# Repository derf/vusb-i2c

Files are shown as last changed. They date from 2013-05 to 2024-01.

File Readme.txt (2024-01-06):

VUSB-based USB to I2C conversion board.

This setup assumes that you have a VUSB board with level conversion on D+ and D-
<http://vusb.wdfiles.com/local--files/hardware/level-conversion-with-zener.gif>,
use an ATTiny and have D+ is connected to INT0, D- to INT1,
SDA to PB6 and SCL to PB7. hardware pull-ups must be connected to SDA and SCL.

The commandline utilities are meant to be similar to the i2c-tools utilities.
vusb-i2cdetect can be used to scan a bus, while vusb-i2cget and vusb-i2cset
read/write data.

For instance, to set a MicroMoody's color to yellow:
> vusb-i2cset 17 0 0 255 255 0 0 1

Or, to read out the temperature from a TC74 thermal sensor:
> vusb-i2cget 77 1 0

The original VUSB readme follows:

-----

This is the README file for the PowerSwitch USB device.

PowerSwitch is an example application using Objective Development's
firmware-only USB driver for Atmel's AVR microcontrollers. It provides 8 bits
of parallel output intended to switch e.g. the power supply to electronic
devices. The PowerSwitch firmware is accompanied by a command line tool to
control the device.

Objective Development's USB driver is a firmware-only implementation of the
USB 1.1 standard (low speed device) on cheap single chip microcomputers of
Atmel's AVR series, such as the ATtiny2313 or even some of the small 8 pin
devices. It implements the standard to the point where useful applications
can be implemented. See the file "firmware/usbdrdv/usbdrv.h" for features
and limitations.

BUILDING AND INSTALLING

Both, the firmware and Unix command line tool are built with "make". You may
need to customize both makefiles.

Firmware:
The firmware for PowerSwitch requires avr-gcc and avr-libc (a C-library for
the AVR controller). Please read the instructions at
http://www.nongnu.org/avr-libc/user-manual/install_tools.html for how to
install the GNU toolchain (avr-gcc, assembler, linker etc.) and avr-libc.
If you are on Windows, download WinAVR (see http://winavr.sourceforge.net/).
For the Mac, we recommend AVR MacPack at http://www.obdev.at/avrmacpack/.

Once you have the GNU toolchain for AVR microcontrollers installed, you can
run "make" in the subdirectory "firmware". You may have to edit the Makefile
to use your preferred downloader with "make flash". Our current version is
built for avrdude with our AVR-Doper programmer.

Command Line Tool on Unix:
The command line tool requires libusb. Please download libusb from
http://libusb.sourceforge.net/ and install it before you compile. Change to
directory "commandline", check the settings in Makefile and edit them as
appropriate. Then type "make" to build the executable "powerSwitch" which can
be used to control the device.

Command Line Tool on Windows:
The command line tool uses libusb-win32. Please download libusb-win32 from
http://libusb-win32.sourceforge.net/. The small package
(libusb-win32-device-bin) should be sufficient. We need usb.h and libusb.a for
gcc (or your favorite compiler). Make sure that usb.h is in the include path
and libusb.a in the library search path (edit Makefile to achieve this).
Although it should be possible to compile the command line tool with any
compiler, we recommend that you use MSYS (to run make and other Unix tools)
and MinGW (for the gcc toolchain). Both can be downloaded for free from
http://www.mingw.org/.

If you want to develop Windows drivers without libusb-win32, see our
"Automator" project for an example.

WORKING WITH POWERSWITCH

Once you have compiled and flashed the firmware and compiled the command line
tool, you can move on to the fun part: Connect the device to a free USB port
of your computer or USB-hub. You should now be able to find the device in
any USB analyzer tool, e.g. SystemProfiler on Mac OS X. If you connect it
to a Windows PC, the "New Hardware" dialog will pop up and you can create
the appropriate info files with libusb-win32's inf-wizard.

The next step is to try the command line tool, e.g.:

    ./powerSwitch off 3

to turn off port 3 (all ports are on when the device has been cleared) or

    for i in 0 1 2 3 4 5 6 7; do ./powerSwitch off $i; done

in an sh or bash (not csh or tcsh) type shell to turn off all ports.

You can also switch a port on or off temporarily. Try

    ./powerSwitch on 0 2.5

to activate port 0 for two and a half seconds.

FILES IN THE DISTRIBUTION

Readme.txt ........ The file you are currently reading.
firmware .......... Source code of the controller firmware.
firmware/usbdrv ... USB driver -- See Readme.txt in this directory for info
commandline ....... Source code of the host software (needs libusb).
circuit ........... Circuit diagrams in PDF and EAGLE 4 format. A free version
                    of EAGLE is available for Linux, Mac OS X and Windows from
                    http://www.cadsoft.de/.
License.txt ....... Public license (GNU GPL2) for all contents of this project.
Changelog.txt ..... Logfile documenting changes in soft-, firm- and hardware.
Pitfalls.txt ...... List of possible pitfalls and solutions.

USING THE USB DRIVER FOR YOUR OWN PROJECTS

PowerSwitch is mainly an example, although it may be very useful by itself.
If you want to implement your own application based on our USB driver, see
the file "firmware/main.c" for the application specific part of the firmware.
PowerSwitch uses only the most basic driver interface. More information and a
full technical description of the driver's interface can be found in
"firmware/usbdrv/usbdrv.h". Please review the configuration options in
"firmware/usbdrv/usbconfig-prototype.h". PowerSwitch uses Objective
Development's free shared USB IDs by default. You may set your own USB IDs
in usbconfig.h. For more information about USB descriptors and IDs see the
document "USB in a Nutshell" available at
http://www.beyondlogic.org/usbnutshell/usb1.htm or the USB 1.1 standard
available at http://www.usb.org/. Don't forget to check the license agreement
for Objective Development's firmware-only USB driver!

ABOUT THE LICENSE

It is our intention to make our USB driver and this demo application
available to everyone. Moreover, we want to make a broad range of USB
projects and ideas for USB devices available to the general public. We
therefore want that all projects built with our USB driver are published
under an Open Source license. Our license for the USB driver and demo code is
the GNU General Public License Version 2 (GPL2). See the file "License.txt"
for details.

If you don't want to publish your source code under the GPL2, you can simply
pay money for AVR-USB. As an additional benefit you get USB PIDs for free,
licensed exclusively to you. See the file "CommercialLicense.txt" for details.

MORE INFORMATION

For more information about Objective Development's firmware-only USB driver
for Atmel's AVR microcontrollers please visit the URL

    http://www.obdev.at/products/avrusb/

A technical documentation of the driver's interface can be found in the file
"firmware/usbdrv/usbdrv.h".

(c) 2005, 2006, 2007 by OBJECTIVE DEVELOPMENT Software GmbH.
http://www.obdev.at/

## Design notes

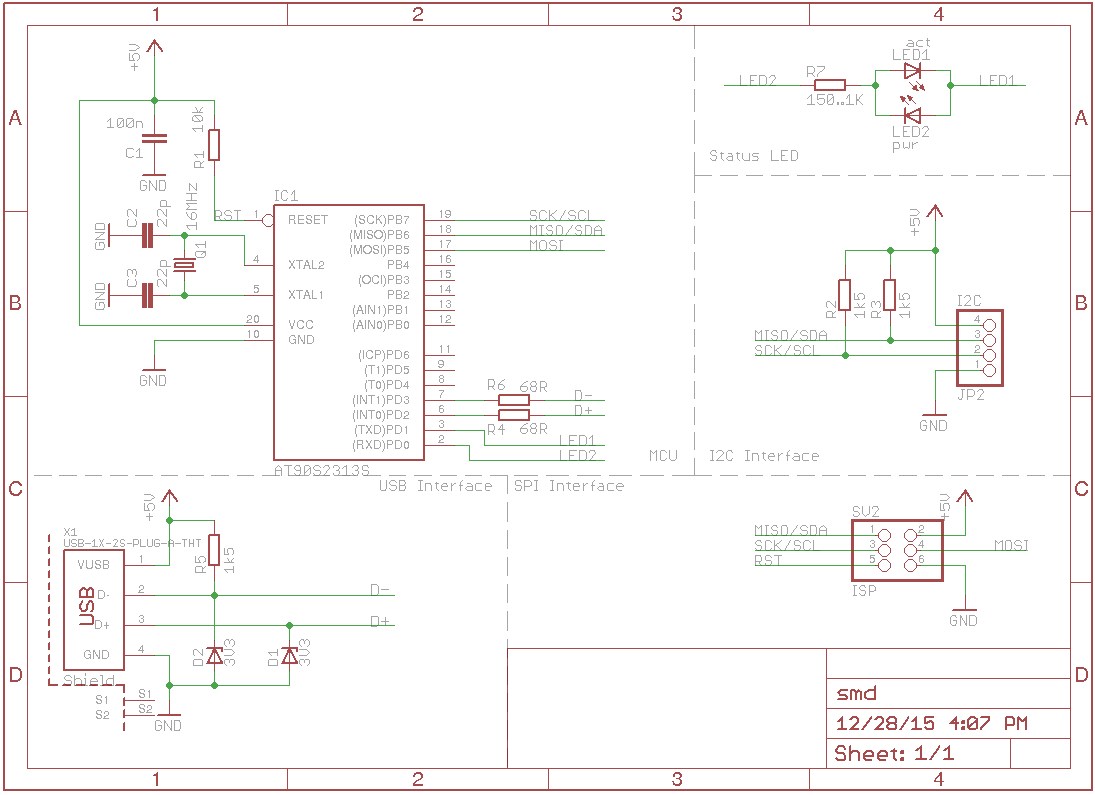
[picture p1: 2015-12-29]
circuit/vusb-i2c-tht.png

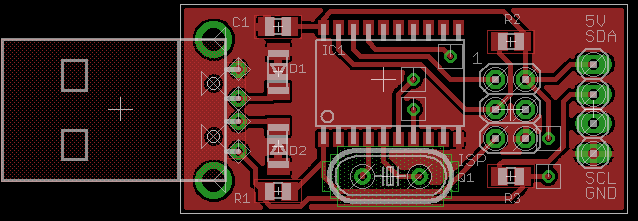
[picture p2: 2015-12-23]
circuit/vusb-i2c-smd.top.png

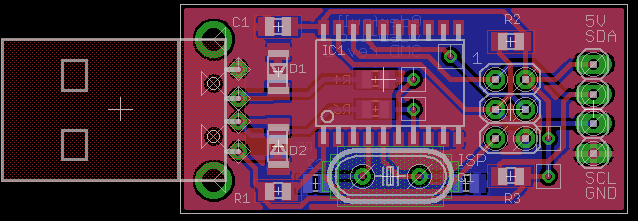
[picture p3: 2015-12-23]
circuit/vusb-i2c-smd.png

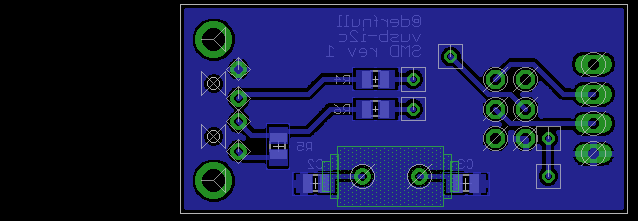
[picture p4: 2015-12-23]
circuit/vusb-i2c-smd.bot.png

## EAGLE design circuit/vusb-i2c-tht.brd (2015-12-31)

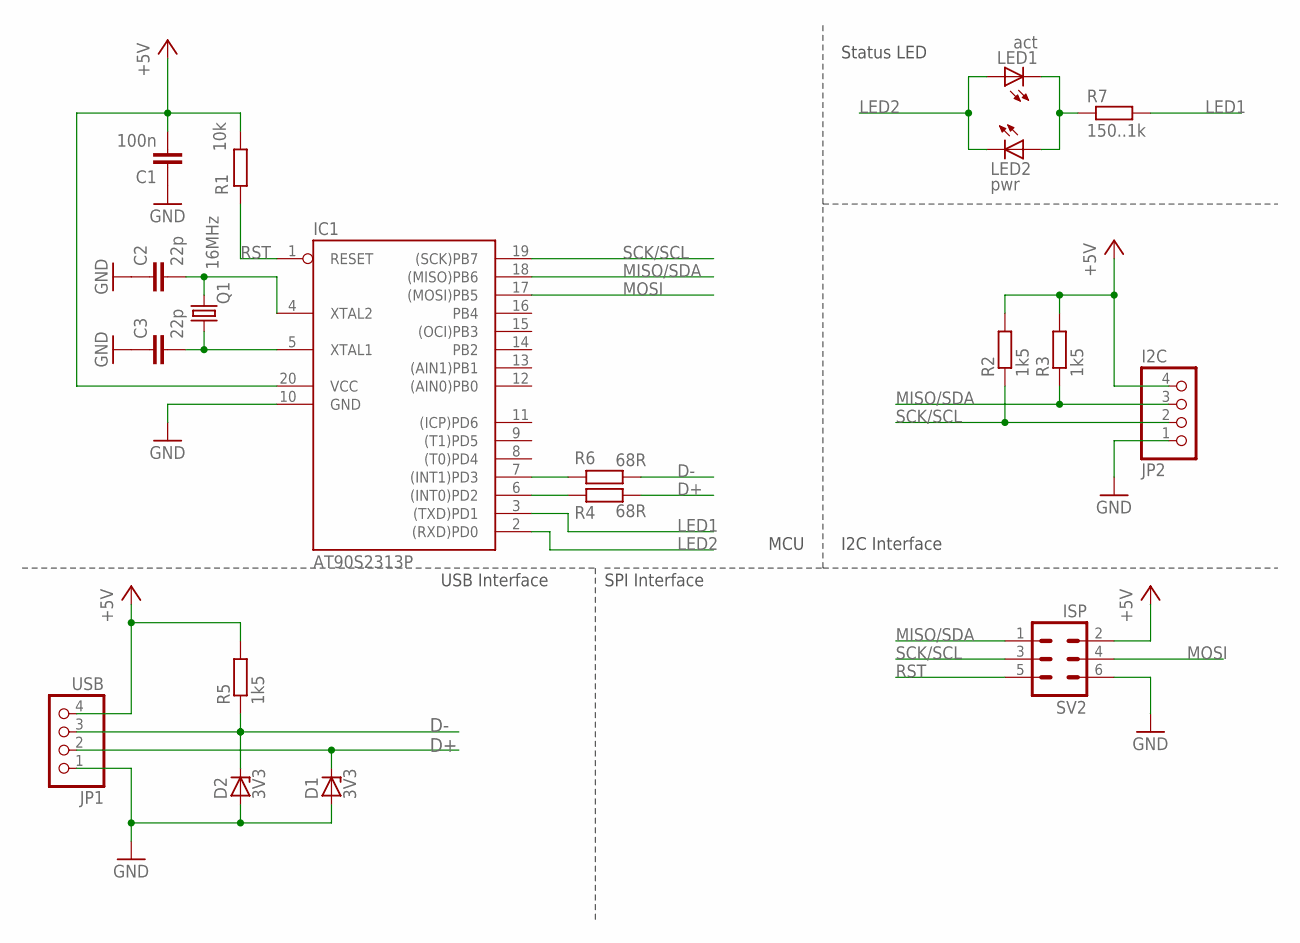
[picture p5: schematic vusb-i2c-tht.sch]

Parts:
C1: 100n; C0805
C2, C3: 22p; C0805
D1, D2: 3V3; DO34Z7
IC1: AT90S2313P; DIL20
JP1: USB; 1X04
JP2: I2C; 1X04
LED1: act; LED3MM
LED2: pwr; LED3MM
Q1: 16MHz; HC49/S
R1: 10k; 0207/10
R2, R3, R5: 1k5; 0207/10
R4, R6: 68R; 0207/10
R7: 150..1k; 0207/10
SV2: ISP; ML6

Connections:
+5V: C1.2, IC1.20 (VCC), JP1.4, JP2.4, R1.2, R2.2, R3.2, R5.2, SV2.2
AVRD+: IC1.6 ((INT0)PD2), R4.2
AVRD-: IC1.7 ((INT1)PD3), R6.2
D+: D1.C, JP1.2, R4.1
D-: D2.C, JP1.3, R5.1, R6.1
EAE: LED1.K (C), LED2.A, R7.1
GND: C1.1, C2.1, C3.1, D1.A, D2.A, IC1.10 (GND), JP1.1, JP2.1, SV2.6
LED1: IC1.3 ((TXD)PD1), R7.2
LED2: IC1.2 ((RXD)PD0), LED1.A, LED2.K (C)
MISO/SDA: IC1.18 ((MISO)PB6), JP2.3, R3.1, SV2.1
MOSI: IC1.17 ((MOSI)PB5), SV2.4
unnamed: C3.2, IC1.5 (XTAL1), Q1.1
unnamed: C2.2, IC1.4 (XTAL2), Q1.2
RST: IC1.1 (RESET), R1.1, SV2.5
SCK/SCL: IC1.19 ((SCK)PB7), JP2.2, R2.1, SV2.3

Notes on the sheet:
USB Interface
MCU
I2C Interface
SPI Interface
Status LED

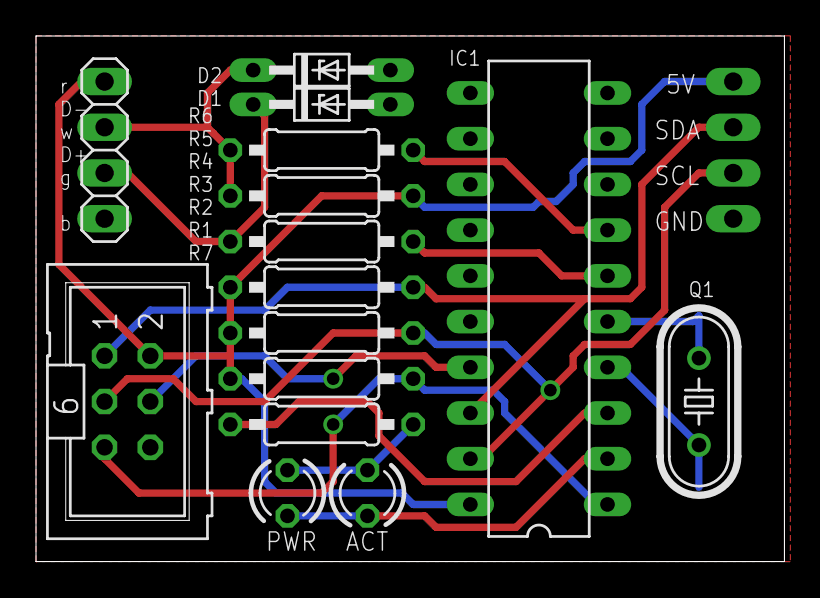
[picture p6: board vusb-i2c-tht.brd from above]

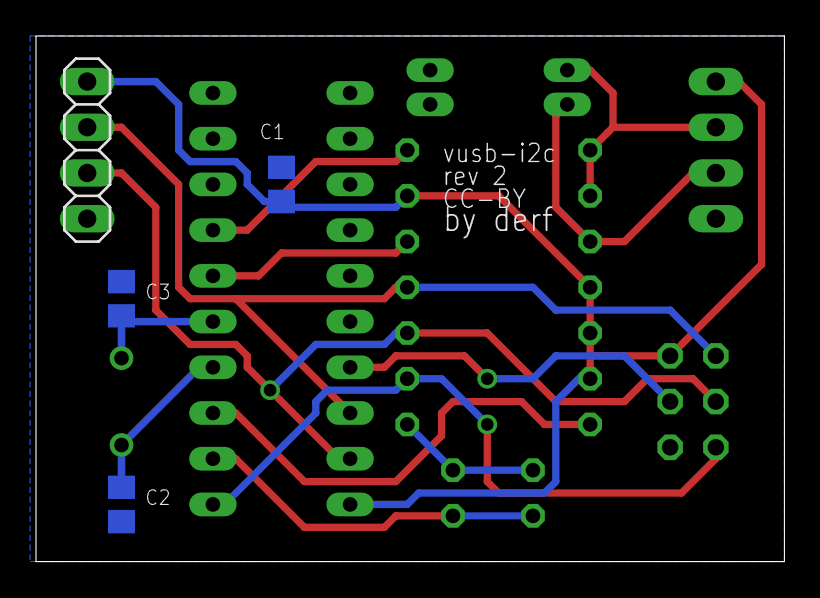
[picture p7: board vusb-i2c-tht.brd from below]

Board: 2 copper layers, 41.6 x 29.2 mm, 19 parts (4 on the bottom side), 15 nets.

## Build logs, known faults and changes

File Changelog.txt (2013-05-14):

This file documents changes in the software, firmware and hardware of the
PowerSwitch device. New entries are always appended to the end of the file.
Scroll down to the bottom to see the most recent changes.

* Release 2005-02-07

- check error returns of libusb functions in commandline/powerSwitch.c
- clarification of section II of the liense
- WinAVR compatibility: do checksize in Makefile as last action because the
  Unix commands fail on Windows.
- WinAVR compatibility: add explicit file type for .S.o rule in Makefile.
- usbdrvasm.S: use a .+0 distance for nop2 macro

* Release 2005-02-20

- Added Pitfalls.txt file documenting common pitfalls.
- Updated usb-driver to new version (in separate directory).
- Use avrlibc init function for watchdog.

* Release 2005-04-18

- Updated usb-driver to new version

* Release 2005-06-14

- Use free shared USB IDs.
- Cleanup in commandline tool Makefile.
- Various improvements in the driver.

* Release 2006-01-31

- Fixed shared product ID in commandline tool.

* Release 2006-02-02

- Fixed usbGetStringAscii() in command line tool (returned random character
  at end of string).
- In usbdrv: New configuration variable to set the segment for USB rx buffer.
- In usbdrv: New configuration options for HIDs.

* Release 2006-02-07

- No changes, we just want to ship the newest driver version with PowerSwitch.

* Release 2006-02-20

- Added IAR compiler compatibility to USB driver (not the PowerSwitch project).
  Thanks to Oleg Semyonov for contributing this port!
- Major Bugfixes in the low level parts of the USB driver. See the driver's
  Changelog for details.

* Release 2006-03-14

- No changes, we just want to ship the newest driver version with PowerSwitch.

* Release 2006-03-26

- Use usb_get_busses() instead of the global usb_busses variable because
  Windows DLLs don't allow global variables from libraries across different
  compilers.

* Release 2006-06-26

- Switched to more general usbOpenDevice() function in commandline tool.

* Release 2006-07-18

- Distribute with GNU GPL2 license.
- Use avrdude instead of uisp as the default downloader.
- New AVR-USB version, see Changelog.txt in firmware/usbdrv/
- Ship with Windows executable and driver by default

* Release 2007-03-29

- Update to new driver.

* Release 2007-06-25

- Updated to new USB driver from 2007-07-07

* Release 2007-07-19

- Update to new driver.
- Use usbRequest_t structure in usbFunctionSetup().
- Fake USB disconnect during reset for at least 500 ms.

* Release 2007-08-07

- Update to newest driver 2007-09-19

* Release 2007-10-23

- Update to newest driver 2007-12-01

* Release 2007-12-01

- Use new usbDeviceDisconnect() and usbDeviceConnect() macros.
- Update to newest driver 2008-01-21.

* Release 2008-01-21

- Updated to newest driver.

* Release 2008-02-05

- Use functions from avr/eeprom.h instead of our own functions. This makes
  the code more portable.
- Updated to newest driver 2008-02-16

* Release 2008-02-16

- Updated to newest driver.

* Release 2008-02-28

- Updated to newest driver.

* Release 2012-12-08

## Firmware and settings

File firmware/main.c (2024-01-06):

/*
 * Copyright (c) 2005 by OBJECTIVE DEVELOPMENT Software GmbH
 *       and (c) 2016 by Birte Friesel
 * License: GNU GPL v2
 */

#include <avr/io.h>
#include <avr/interrupt.h>
#include <avr/pgmspace.h>
#include <avr/wdt.h>

#include "usbdrv.h"
#include "oddebug.h"
#include <util/delay.h>

USB_PUBLIC uchar usbFunctionSetup(uchar data[8])
{
	usbRequest_t    *rq = (void *)data;
	static uchar    replyBuf[2];
	static uchar    bv_sda, bv_scl; // bit vector, e.g. 0b01000000 for bit6
	static uchar    i;
	static uchar    buf; // r/w buffer for wValue.bytes[0]

	usbMsgPtr = replyBuf;

	if (rq->bRequest == USBCMD_ECHO) {
		replyBuf[0] = rq->wValue.bytes[0];
		replyBuf[1] = rq->wValue.bytes[1];
		return 2;
	}
	if (rq->bRequest == USBCMD_GETPORT) {
		replyBuf[0] = PINB;
		return 1;
	}
	if (rq->bRequest == USBCMD_SETPORT) {
		DDRB = ~(rq->wIndex.bytes[0]);
		return 0;
	}
	if (rq->bRequest == USBCMD_SETBITS) {
		bv_sda = rq->wIndex.bytes[0];
		bv_scl = rq->wIndex.bytes[1];
		return 0;
	}
	if (rq->bRequest == USBCMD_START) {
		DDRB &= ~(bv_sda | bv_scl);
		_delay_us(1000);
		DDRB |= bv_sda;
		_delay_us(1000);
		DDRB |= bv_scl;
		return 0;
	}
	if (rq->bRequest == USBCMD_STOP) {
		DDRB |= bv_sda;
		_delay_us(100);
		DDRB &= ~bv_scl;
		_delay_us(100);
		DDRB &= ~bv_sda;
		_delay_us(100);
		return 0;
	}
	if (rq->bRequest == USBCMD_TX) {
		buf = rq->wIndex.bytes[0]; // byte to transmit
		for (i = 0; i <= 8; i++) {
			if ((buf & 0x80) || (i == 8)) {
				DDRB &= ~bv_sda;
			} else {
				DDRB |= bv_sda;
			}
			buf <<= 1;
			_delay_us(100);
			DDRB &= ~bv_scl;
			_delay_us(100);
			if (i == 8) {
				if (PINB & bv_sda) {
					replyBuf[0] = 0;
				} else {
					replyBuf[0] = 1;
				}
			}
			DDRB |= bv_scl;
			_delay_us(100);
		}
		return 1;
	}
	if (rq->bRequest == USBCMD_RX) {
		buf = rq->wIndex.bytes[0]; // true <=> transmit ack
		DDRB &= ~bv_sda;
		replyBuf[0] = 0;
		for (i = 0; i <= 8; i++) {
			_delay_us(20);
			DDRB &= ~bv_scl;
			_delay_us(20);
			if ((i < 8) && ( PINB & bv_sda)) {
				replyBuf[0] |= _BV(7-i);
			}
			_delay_us(20);
			DDRB |= bv_scl;
			_delay_us(20);
			if ((i == 7) && buf) {
				DDRB |= bv_sda;
			}
			else if ((i == 8) && buf) {
				DDRB &= ~bv_sda;
			}
		}
		return 1;
	}
	return 0;
}

/* allow some inter-device compatibility */
#if !defined TCCR0 && defined TCCR0B
#define TCCR0   TCCR0B
#endif
#if !defined TIFR && defined TIFR0
#define TIFR    TIFR0
#endif

int main(void)
{
	uchar   i;

	wdt_enable(WDTO_1S);
	odDebugInit();
	DDRB = 0;
	DDRD = ~USBMASK;   /* all outputs except PD2 = INT0 */
	PORTD = 0;
	PORTB = 0;          /* no pullups on USB pins */
	/* We fake an USB disconnect by pulling D+ and D- to 0 during reset. This is
	* necessary if we had a watchdog reset or brownout reset to notify the host
	* that it should re-enumerate the device. Otherwise the host's and device's
	* concept of the device-ID would be out of sync.
	*/
	usbDeviceDisconnect();  /* enforce re-enumeration, do this while interrupts are disabled! */
	i = 0;
	while(--i){         /* fake USB disconnect for > 500 ms */
		wdt_reset();
		_delay_ms(2);
	}
	usbDeviceConnect();
	TCCR0 = 5;          /* set prescaler to 1/1024 */
	usbInit();
	PORTD = _BV(1); /* turn on power LED */
	sei();
	for(;;){    /* main event loop */
		wdt_reset();
		usbPoll();
		if (TIFR & (1 << TOV0)){
			TIFR |= 1 << TOV0;  /* clear pending flag */
		if (PINB & _BV(PB7))
			PORTD = _BV(1); /* SCL high : turn on power LED */
		else
			PORTD = _BV(0); /* SCL low (busy) : turn on activity LED */
		}
	}
	return 0;
}

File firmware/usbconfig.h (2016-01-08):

/* Name: usbconfig.h
 * Project: AVR USB driver
 * Author: Christian Starkjohann
 * Creation Date: 2005-04-01
 * Tabsize: 4
 * Copyright: (c) 2005 by OBJECTIVE DEVELOPMENT Software GmbH
 * License: GNU GPL v2 (see License.txt) or proprietary (CommercialLicense.txt)
 * This Revision: $Id: usbconfig.h 43 2005-04-10 21:04:36Z cs $
 */

#ifndef __usbconfig_h_included__
#define __usbconfig_h_included__

#include "../global_config.h"

/*
General Description:
This file contains parts of the USB driver which can be configured and can or
must be adapted to your hardware.

Please note that the usbdrv contains a usbconfig-prototype.h file now. We
recommend that you use that file as a template because it will always list
the newest features and options.
*/

/* ---------------------------- Hardware Config ---------------------------- */

#define USB_CFG_CLOCK_KHZ       (F_CPU/1000)

#define USB_CFG_IOPORTNAME      D
/* This is the port where the USB bus is connected. When you configure it to
 * "B", the registers PORTB, PINB and DDRB will be used.
 */
#define USB_CFG_DMINUS_BIT      3
/* This is the bit number in USB_CFG_IOPORT where the USB D- line is connected.
 * This may be any bit in the port.
 */
#define USB_CFG_DPLUS_BIT       2
/* This is the bit number in USB_CFG_IOPORT where the USB D+ line is connected.
 * This may be any bit in the port. Please note that D+ must also be connected
 * to interrupt pin INT0!
 */
/* #define USB_CFG_CLOCK_KHZ       (F_CPU/1000) */
/* Clock rate of the AVR in MHz. Legal values are 12000, 16000 or 16500.
 * The 16.5 MHz version of the code requires no crystal, it tolerates +/- 1%
 * deviation from the nominal frequency. All other rates require a precision
 * of 2000 ppm and thus a crystal!
 * Default if not specified: 12 MHz
 */

/* ----------------------- Optional Hardware Config ------------------------ */

/* #define USB_CFG_PULLUP_IOPORTNAME   D */
/* If you connect the 1.5k pullup resistor from D- to a port pin instead of
 * V+, you can connect and disconnect the device from firmware by calling
 * the macros usbDeviceConnect() and usbDeviceDisconnect() (see usbdrv.h).
 * This constant defines the port on which the pullup resistor is connected.
 */
/* #define USB_CFG_PULLUP_BIT          4 */
/* This constant defines the bit number in USB_CFG_PULLUP_IOPORT (defined
 * above) where the 1.5k pullup resistor is connected. See description
 * above for details.
 */

/* --------------------------- Functional Range ---------------------------- */
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

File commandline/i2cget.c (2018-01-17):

#include <unistd.h>
#include <stdio.h>
#include <stdlib.h>
#include <string.h>
#include "i2c-util.h"

int main(int argc, char **argv)
{
	int i, address, cmdbuf;
	int num_bytes = 1;
	unsigned int ret;
	char *conv_err;

	i2c_getopt(argc, argv);

	if (argc < 3) {
		fputs("Usage: vusb-i2cget <address> <num_bytes> [register ...] ", stderr);
		return 1;
	}

	address = strtol(argv[1], &conv_err, 0);

	if (conv_err && *conv_err) {
		fprintf(stderr, "address: Conversion error at '%s'\n", conv_err);
		return 2;
	}

	num_bytes = strtol(argv[2], &conv_err, 0);

	if (conv_err && *conv_err) {
		fprintf(stderr, "num_bytes: Conversion error at '%s'\n", conv_err);
		return 2;
	}

	i2c_init();

	if (argc >= 3) {
		i2c_hw_start();

		if (!i2c_hw_tx_byte((address << 1) | 0)) {
			fprintf(stderr, "Received NAK from slave 0x%02x, aborting\n", address);
			i2c_hw_stop();
			i2c_deinit();
			return 3;
		}
	}

	for (i = 3; i < argc; i++) {
		cmdbuf = strtol(argv[i], &conv_err, 0);
		if (conv_err && *conv_err) {
			fprintf(stderr, "read command: Conversion error at '%s'\n", conv_err);
			i2c_hw_stop();
			i2c_deinit();
			return 2;
		}
		if (!i2c_hw_tx_byte(cmdbuf)) {
			fprintf(stderr, "Received NAK after byte %d (0x%02x)\n", i-1, cmdbuf);
			i2c_hw_stop();
			i2c_deinit();
			return 4;
		}
	}

	i2c_hw_start();
	if (!i2c_hw_tx_byte((address << 1) | 1)) {
		fprintf(stderr, "Received NAK after reSTART from slave 0x%02x, aborting\n", address);
		i2c_hw_stop();
		i2c_deinit();
		return 3;
	}

	for (i = 1; i <= num_bytes; i++) {
		printf("%i ", i2c_hw_rx_byte((i < num_bytes) * 1));
	}
	putc('\n', stdout);

	i2c_hw_stop();
	i2c_deinit();

	return 0;
}

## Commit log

2013-05-17 rename powerSwitch to i2c (more accurate)
2013-06-07 leave space for ninth i2c (ack) bit
2013-06-29 firmware: fix initialization, disable software pull-ups, fix readout
    [main.c]
2013-06-29 firmware: i2c is high by default
2013-06-30 now 100% i2c compliant. use "256" to read a byte
2013-07-16 add i2cdetect
2013-07-28 move common code to i2c-util.c
2013-07-28 add vusb-i2cwrite
2013-07-28 add vusb-i2cget
2013-07-28 rename i2cwrite to i2cset for i2c-tools compatibility
2013-07-29 i2cget: read 16bit ints as well
2013-08-02 i2cdetect cleanup
2013-10-03 i2cget / i2cset: Accept hexadecimal input, document exit codes
2013-10-03 i2cdetect: Send START without prior STOP
2013-10-04 i2cset: use strtol for all conversions
2013-10-04 i2cget: Allow read commands of arbitrary length
2015-11-25 circuit: start work on board layout
    [circuit.brd, circuit.sch]
2015-11-26 more baord layout improvements
    [circuit.brd]
2015-11-26 such layout, wow
    [circuit.brd, circuit.sch]
2015-12-21 more layouting
    [circuit.brd, circuit.sch]
2015-12-22 circuit: proper schematic
    [circuit.brd, circuit.sch]
2015-12-22 circuit: Also, design rules...
    [circuit.brd]
2015-12-23 add first draft of SMD circuit
    [smd.brd, smd.sch]
2015-12-23 further refinements
    [smd.brd]
2015-12-24 i2cget, i2cset: more error handling
    [i2cget.c, i2cset.c]
2015-12-27 smd layout: add status LEDs, cause status LEDs are always good \o/
    [smd.brd, smd.sch]
2015-12-29 smd rev 1 at board house
    [smd.brd, smd.sch]
2015-12-29 tht circuit: preparing rev 2
    [circuit.brd, circuit.sch]
2015-12-30 THT circuit: Adjust label placement
    [circuit.brd]
2015-12-30 circuits: normalize file names
    [vusb-i2c-smd.brd, vusb-i2c-smd.sch, vusb-i2c-tht.brd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]
2015-12-31 vusb-i2c-tht layout: Add a missing wire
    [vusb-i2c-tht.brd]
2016-01-01 normalize firmware/Makefile (and always run make fuse_tiny2313)
2016-01-01 commandline: remove legacy 'vusb-i2c' program
2016-01-02 firmware: add support for power/activity LEDs
2016-01-02 i2cget, i2cset: properly terminate I2C connection in case of errors
    [i2cget.c, i2cset.c]
2016-01-09 move software I2C implementation to ATTiny
2016-01-10 firmware: clean up main.c, remove driver size test code
2016-01-30 firmware: Fix LED polarity mixup
    [main.c]
2016-12-25 i2cget: support multi-byte reads
2016-12-25 add example script for lm75 temperature sensors
2016-12-26 Firmware: Fix ACK in RX mode
    [main.c]
2018-01-17 i2cget: Support reads without prior register address write
2018-01-17 Add example for reading out AM2320 temperature and humidity sensor
2021-04-08 add ssd1306 (I2C OLED display) examples
2024-01-06 adjust ds2482-100 examples for vusb-i2cget multi-byte support
2024-01-06 Adjust Readme for vusb-i2cget multi-byte support

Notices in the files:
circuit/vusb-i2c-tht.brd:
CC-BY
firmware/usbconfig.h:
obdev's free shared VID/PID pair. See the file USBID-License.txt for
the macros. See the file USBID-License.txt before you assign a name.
